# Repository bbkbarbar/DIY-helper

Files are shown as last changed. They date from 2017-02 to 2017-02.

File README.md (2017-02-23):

# DIY-helper
..is a arduino based distance meter tool <br> with 4 distance sensors looks "up", "down", left and right, to help positioning things on the wall (e.g.: picture frames) or on the floor.

[The original idea found on this video.](https://youtu.be/QvjQSEvRNkw)

### Planned features:

 - Simple distance measurement
 - Distance measurement in 2 opposite side (can select direction [left-right / up-down])
 - Positioning: continously show the distance values in real time (measure from middle hole or from the side)
    - Can "store" the position and measure distance from that point
 - Area calculation (can select display unit (cm2 or m2 -usefull for wall painting-))

### Used libraries:
 - For handling more push-buttons on 1 single ADC input: [ButtonHandler-library](https://bbkbarbar.github.io/Arduino-ButtonHandler-library/)
 - For handling OLED display over softSpi bus: [SSD1306Ascii-library](https://bbkbarbar.github.io/Arduino-SSD1306Ascii/)
 - For handling HC-SR04 distance sensor: [HC-SR04 library](https://bbkbarbar.github.io/Arduino-HC-SR04-library/)

### Custom modules:
 - Main board (as arduino nano shield) [schematic](https://github.com/bbkbarbar/DIY-helper/blob/master/Docs/mail_board.png), [pcb design](https://github.com/bbkbarbar/DIY-helper/blob/master/Docs/mail_board_pcb.png), [pcb design as .pdf](https://github.com/bbkbarbar/DIY-helper/raw/master/Eagle/DIY_tool_-_Arduino_nano_shield_pcb_v1.1.pdf)
 - Button board [schematic](https://github.com/bbkbarbar/DIY-helper/blob/master/Docs/button_board.png), [pcb design](https://github.com/bbkbarbar/DIY-helper/blob/master/Docs/button_board_pcb.png), [pcb design as .pdf](https://github.com/bbkbarbar/DIY-helper/raw/master/Eagle/DIY_tool_-_button_panel_pcb_v1.pdf)

### ToDo list:
- [x] Clarify / finalyze planned features
- [x] Create test circuits on bread-boards for handling multiple buttons on 1 ADC input
- [x] Try out to use multiple buttons in 1 ADC line
- [x] Create schematic for main board
- [x] Create schematic for button board according to the planned features (e.g.: count of push-buttons)
- [x] Create PCB design for main board
- [x] Create PCB design for button board
- [ ] Finalyze part-list and buy missing parts (if there any)
- [ ] Create test circuits on bread-boards for complete project
- [ ] Create plans for "UI"
- [ ] Create the "RC"-version from firmware
- [ ] <b>After first working bread-board prototype:</b>
- [ ] Create case-design
- [ ] Decide about used materials
- [ ] Build final version in proper case.

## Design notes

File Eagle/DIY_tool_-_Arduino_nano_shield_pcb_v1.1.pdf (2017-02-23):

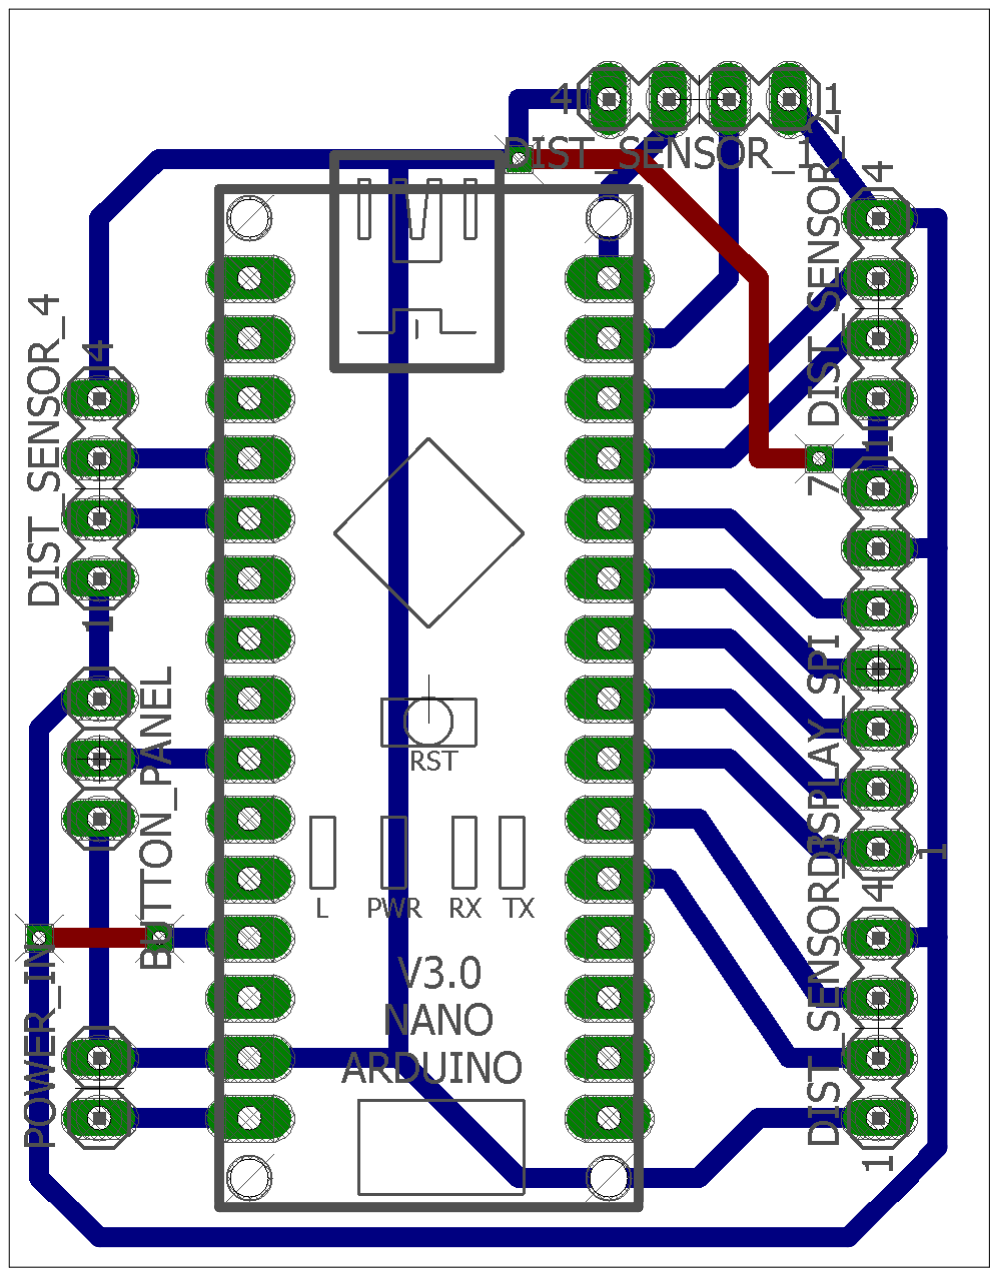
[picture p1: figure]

2017.02.23. 6:39 f:\Dokumentumok\eagle\DIY-tool\DIY-tool\DIY_tool_-_Arduino_nano_shield_v1.1.brd

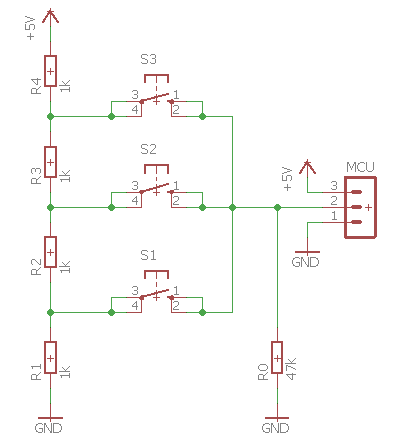
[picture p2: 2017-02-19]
Docs/button_board.png

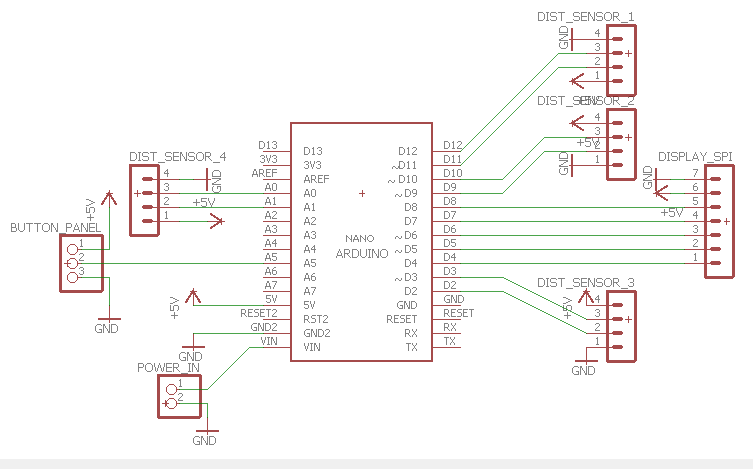
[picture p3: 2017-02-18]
Docs/mail_board.png

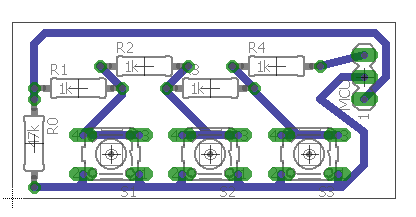
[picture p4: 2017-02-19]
Docs/button_board_pcb.png

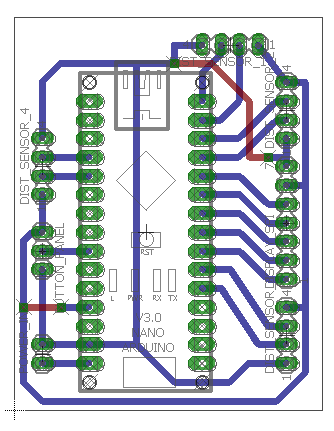
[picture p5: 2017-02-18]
Docs/mail_board_pcb.png

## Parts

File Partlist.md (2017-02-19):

# Used modules:

| Module name | type |quantity |
| :--- | :--- | :-----: |
| Arduino nano | MCU / board | 1 |
| HC-SR04 | sensor | 4 |
| OLED display (SPI) | output | 1 |
| Button panel | input | 1 |
| Pointer laser | output | 1 |

Needed parts:

| Name, value | type | quantity | note |
| :--- | :----- | :---: | :---: |
| Main board | | | custom pcb |
| Female pin header | 1*15 | 2 | for arduino |
| Male pin header | 1*4 | 4 | for HC-SR04 sensors |
| Male pin header | 1*7 | 1 | for OLED display |
| Button board | | | custom pcb |
| Push button | | 3? | |
| Resistor: 330 - 1k  | | 4 | for voltage divider |
| Resistor: 10k - 47k | | 1 | for adc pull-down |
| Transistor ? | | 1 | To turn on/off pointer |
| Battery connector | | 1 | (planned battery type: 9V) |
| Battery | | 1 | 9V |

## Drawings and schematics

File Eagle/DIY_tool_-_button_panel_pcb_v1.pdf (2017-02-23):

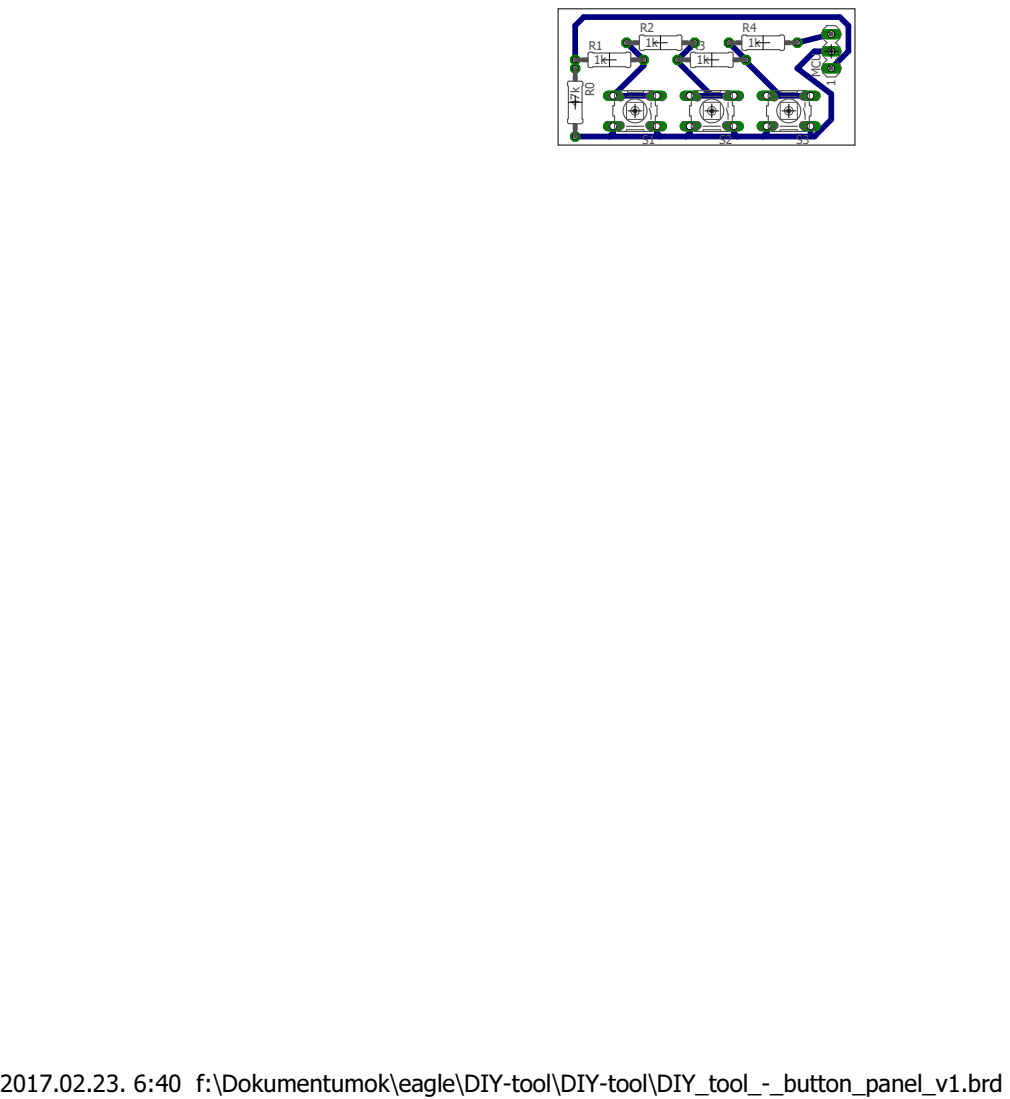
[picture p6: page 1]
3MCU

2017.02.23. 6:40 f:\Dokumentumok\eagle\DIY-tool\DIY-tool\DIY_tool_-_button_panel_v1.brd

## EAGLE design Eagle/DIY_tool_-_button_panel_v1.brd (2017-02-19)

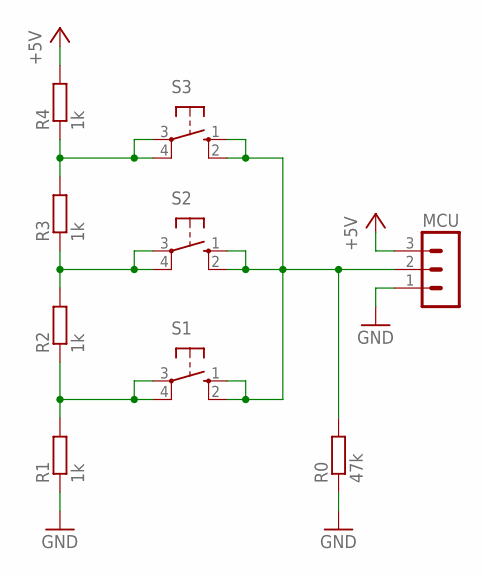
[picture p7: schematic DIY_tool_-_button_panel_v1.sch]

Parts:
MCU: MA03-1
R0: 47k; 0207/10
R1, R2, R3, R4: 1k; 0207/10
S1, S2, S3: 10-XX; B3F-10XX

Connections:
+5V: MCU.3, R4.2
ADC: MCU.2, R0.2, S1.1 (S), S1.2 (S1), S2.1 (S), S2.2 (S1), S3.1 (S), S3.2 (S1)
B1: R1.2, R2.1, S1.3, S1.4 (P1)
B2: R2.2, R3.1, S2.3, S2.4 (P1)
B3: R3.2, R4.1, S3.3, S3.4 (P1)
GND: MCU.1, R0.1, R1.1

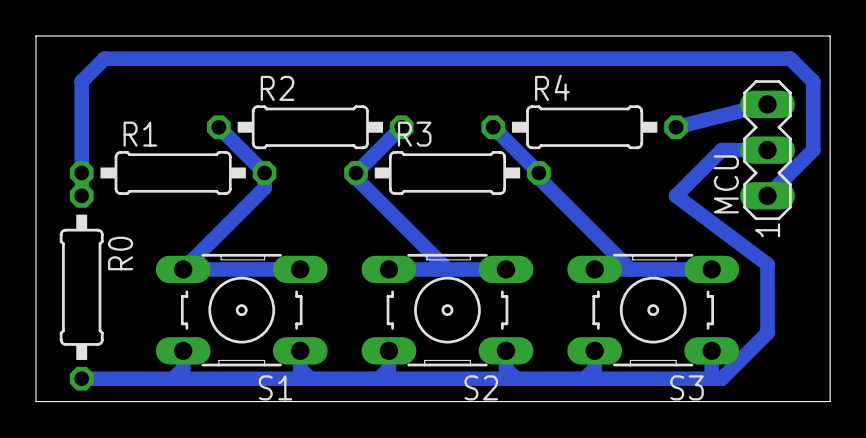
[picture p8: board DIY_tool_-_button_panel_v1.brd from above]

Board: 2 copper layers, 44.1 x 20.3 mm, 9 parts (0 on the bottom side), 6 nets.

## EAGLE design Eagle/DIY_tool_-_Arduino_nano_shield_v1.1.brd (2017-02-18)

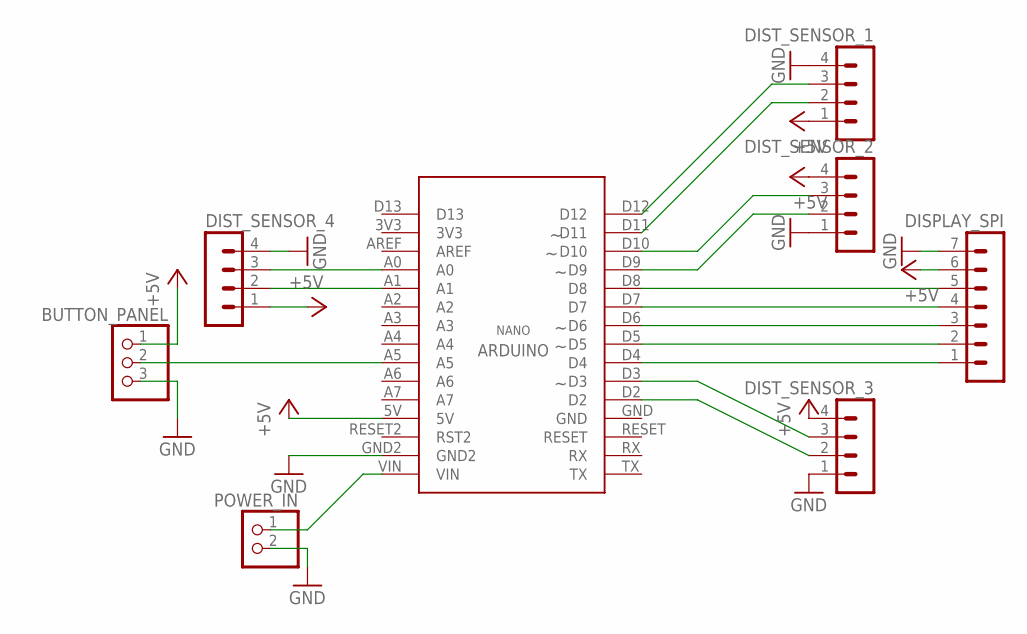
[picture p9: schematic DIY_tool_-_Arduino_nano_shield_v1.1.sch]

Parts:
BUTTON_PANEL: PINHD-1X3; 1X03
DISPLAY_SPI: MA07-1
DIST_SENSOR_1, DIST_SENSOR_2, DIST_SENSOR_3, DIST_SENSOR_4: MA04-1
POWER_IN: PINHD-1X2; 1X02
U$2: NANO

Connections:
+5V: BUTTON_PANEL.1, DISPLAY_SPI.6, DIST_SENSOR_1.1, DIST_SENSOR_2.4, DIST_SENSOR_3.4, DIST_SENSOR_4.1, U$2.5V
BTN_IN: BUTTON_PANEL.2, U$2.A5
GND: BUTTON_PANEL.3, DISPLAY_SPI.7, DIST_SENSOR_1.4, DIST_SENSOR_2.1, DIST_SENSOR_3.1, DIST_SENSOR_4.4, POWER_IN.2, U$2.GND2
OLED_CS: DISPLAY_SPI.1, U$2.D4
OLED_D0: DISPLAY_SPI.5, U$2.D8
OLED_D1: DISPLAY_SPI.4, U$2.D7
OLED_DC: DISPLAY_SPI.2, U$2.D5
OLED_RST: DISPLAY_SPI.3, U$2.D6
POWER_IN: POWER_IN.1, U$2.VIN
SENSOR_1_A: DIST_SENSOR_1.3, U$2.D12
SENSOR_1_B: DIST_SENSOR_1.2, U$2.D11
SENSOR_2_A: DIST_SENSOR_2.3, U$2.D10
SENSOR_2_B: DIST_SENSOR_2.2, U$2.D9
SENSOR_3_A: DIST_SENSOR_3.3, U$2.D3
SENSOR_3_B: DIST_SENSOR_3.2, U$2.D2
SENSOR_4_A: DIST_SENSOR_4.3, U$2.A0
SENSOR_4_B: DIST_SENSOR_4.2, U$2.A1

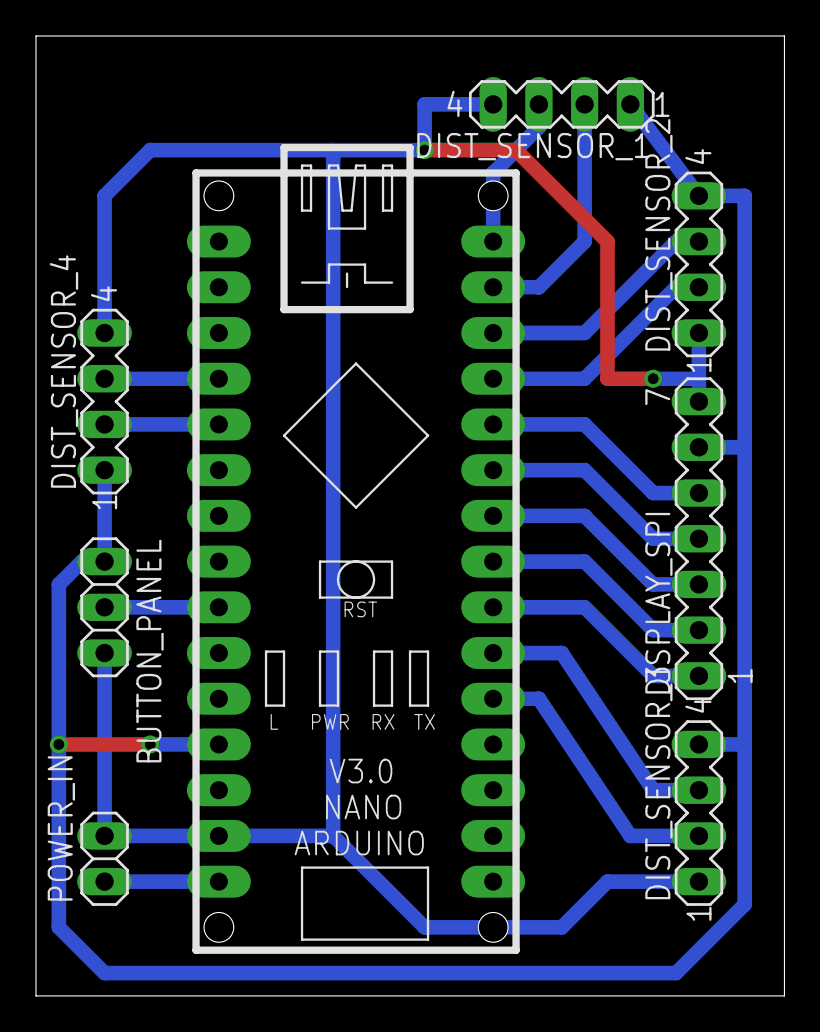
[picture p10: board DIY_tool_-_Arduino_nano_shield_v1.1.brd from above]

Board: 2 copper layers, 41.6 x 53.3 mm, 8 parts (0 on the bottom side), 17 nets.

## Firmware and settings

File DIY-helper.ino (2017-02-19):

#include <buttonhandler.h>

// Pin definitions
//   Display
#define OLED_D0              8
#define OLED_D1              7
#define OLED_RST             6
#define OLED_DC              5
#define OLED_CS              4
  
//   Buttons  
#define ADC_FOR_BUTTONS     A5

//   Disctance sensors


// Buttons
#define NUMBER_OF_BUTTONS    3
#define BTN1                 1
#define BTN2                 2
#define BTN3                 3

// Modes
#define MODE_COUNT           4
#define MODE_SDM             0
#define MODE_OSM             1
#define MODE_POS             2
#define MODE_AREA            3

// Directions
#define DIRECTION_UP         0
#define DIRECTION_RIGHT      1
#define DIRECTION_DOWN       2
#define DIRECTION_LEFT       3

#define DIRECTION_VERTICAL   4
#define DIRECTION_HORIZONTAL 5


#include <SSD1306Ascii.h>
#include <SSD1306AsciiSoftSpi.h>

// Global variables

ButtonHandler buttons;
SSD1306AsciiSoftSpi oled;


// Functions

void setup() {

  buttons.init(ADC_FOR_BUTTONS, NUMBER_OF_BUTTONS);

  oled.begin(&Adafruit128x64, OLED_CS, OLED_DC, OLED_D0, OLED_D1, OLED_RST);
  oled.setFont(Adafruit5x7);
  oled.clear();
  oled.set2X();
  
}


void loop() {



}

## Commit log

2017-02-18 Add schematic and pcb design for mainboard
    [DIY_tool_-_Arduino_nano_shield_v1.1.brd, DIY_tool_-_Arduino_nano_shield_v1.1.sch]
2017-02-18 Add library link for disctance sensor
2017-02-19 Add button board schematic and pcb design
2017-02-19 Add lins for button board schematic and pcb design
2017-02-19 Table for finalize modes and button functions
    [Modes.xlsx]
2017-02-19 Add board schematic and pcb design
    [DIY_tool_-_Arduino_nano_shield_v1.sch, DIY_tool_-_button_panel_v1.brd, DIY_tool_-_button_panel_v1.sch]
2017-02-23 Add pcb designs as .pdf
2017-02-23 Add links for pcb design pdfs
